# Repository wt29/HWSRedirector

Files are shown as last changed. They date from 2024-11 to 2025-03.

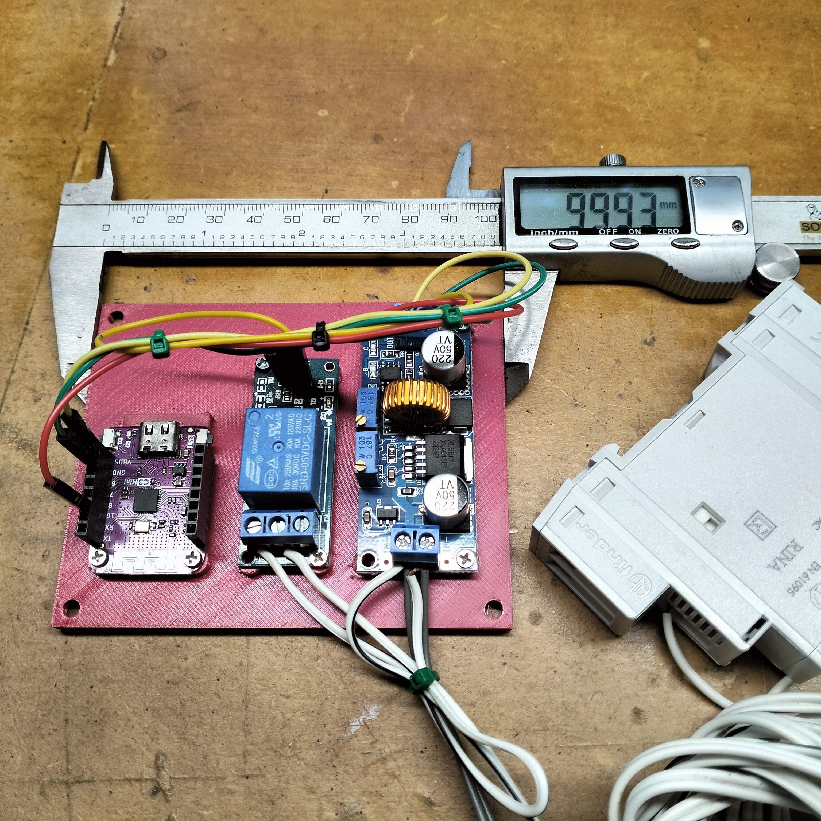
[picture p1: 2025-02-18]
IMG20250219094051.jpg

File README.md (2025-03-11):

# Hot Water System Redirector

Uses a 240V 25A contactor (with 12V triggering) to switch a resistive HWS into direct connection to the exported (from solar) grid. My
basic reason for this is - Heat Pumps are great for outright efficiency but are mechanical, expensive and will eventually wear out. A resistive HWS coupled with a 
decent sized solar array should be a better fit for a many homes (IMHO) especially those with limited funds for HPHWS installation.

This sketch uses an API to read from a power monitoring system - I use an IOTAWATT however it also has a "Shelly EM" interface as well.

If you are using EMONCMS as your data capture and management system, this will also log the changes there.

The sketch uses a small data.h file to store local values. It also allows me to upload this project without revealing local data. 
There is a template in the header of main.cpp. 

You can adjust the threshold value and the "wait time" depending on your local requirement.

Its currently set up for an Espressif ESP32 C3 (I use the LOLIN C3 Mini) however any ESP microcontroller should work. It assumes
the power monitoring is available via Wifi (they aren't much use without it).

Here is a basic BOM  

1. An ESP32/8266 with WiFi (they all have them) - I used a Lolin C3 Mini but almost any ESP thing would work. https://www.aliexpress.com/item/1005004740051202.html
2. 25A Contactor with 12V trigger - I used a "Finder 22.32" with both NC and NO contacts
3. 12V power supply - a 1A wall wart will do the job fine.
4. Small DC-DC converter to provide 5V to the ESP - https://core-electronics.com.au/dc-dc-adjustable-step-down-module-5a-75w.html  as an example
5. An Arduino style relay - https://core-electronics.com.au/5v-single-channel-relay-module-10a.html
6. Some sort of enclosure - this is only 12V and mounted outside the swithwoard so weather proofing is the main aim here.

Get a local sparky to hook up the contactor and required isolators. They can also expose the 12V terminals somewhere you can get to them outside the board. You may as well get them to install a local power point as well.

The repo contains a Fusion (360) project and STL to build a mounting board for the 3 electronic boards. There is also the KiCAD files for the (somewhat) basic circuit involved.

This project is also under a bit of occasional development, mainly around getting a small UI on it.

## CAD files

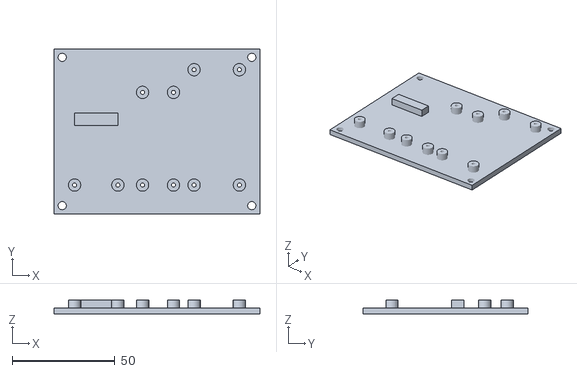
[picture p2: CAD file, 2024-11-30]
mount/HWSMount.stl
100.0 x 80.0 x 7.00

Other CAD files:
mount/HWS Redirector mount v5.f3d

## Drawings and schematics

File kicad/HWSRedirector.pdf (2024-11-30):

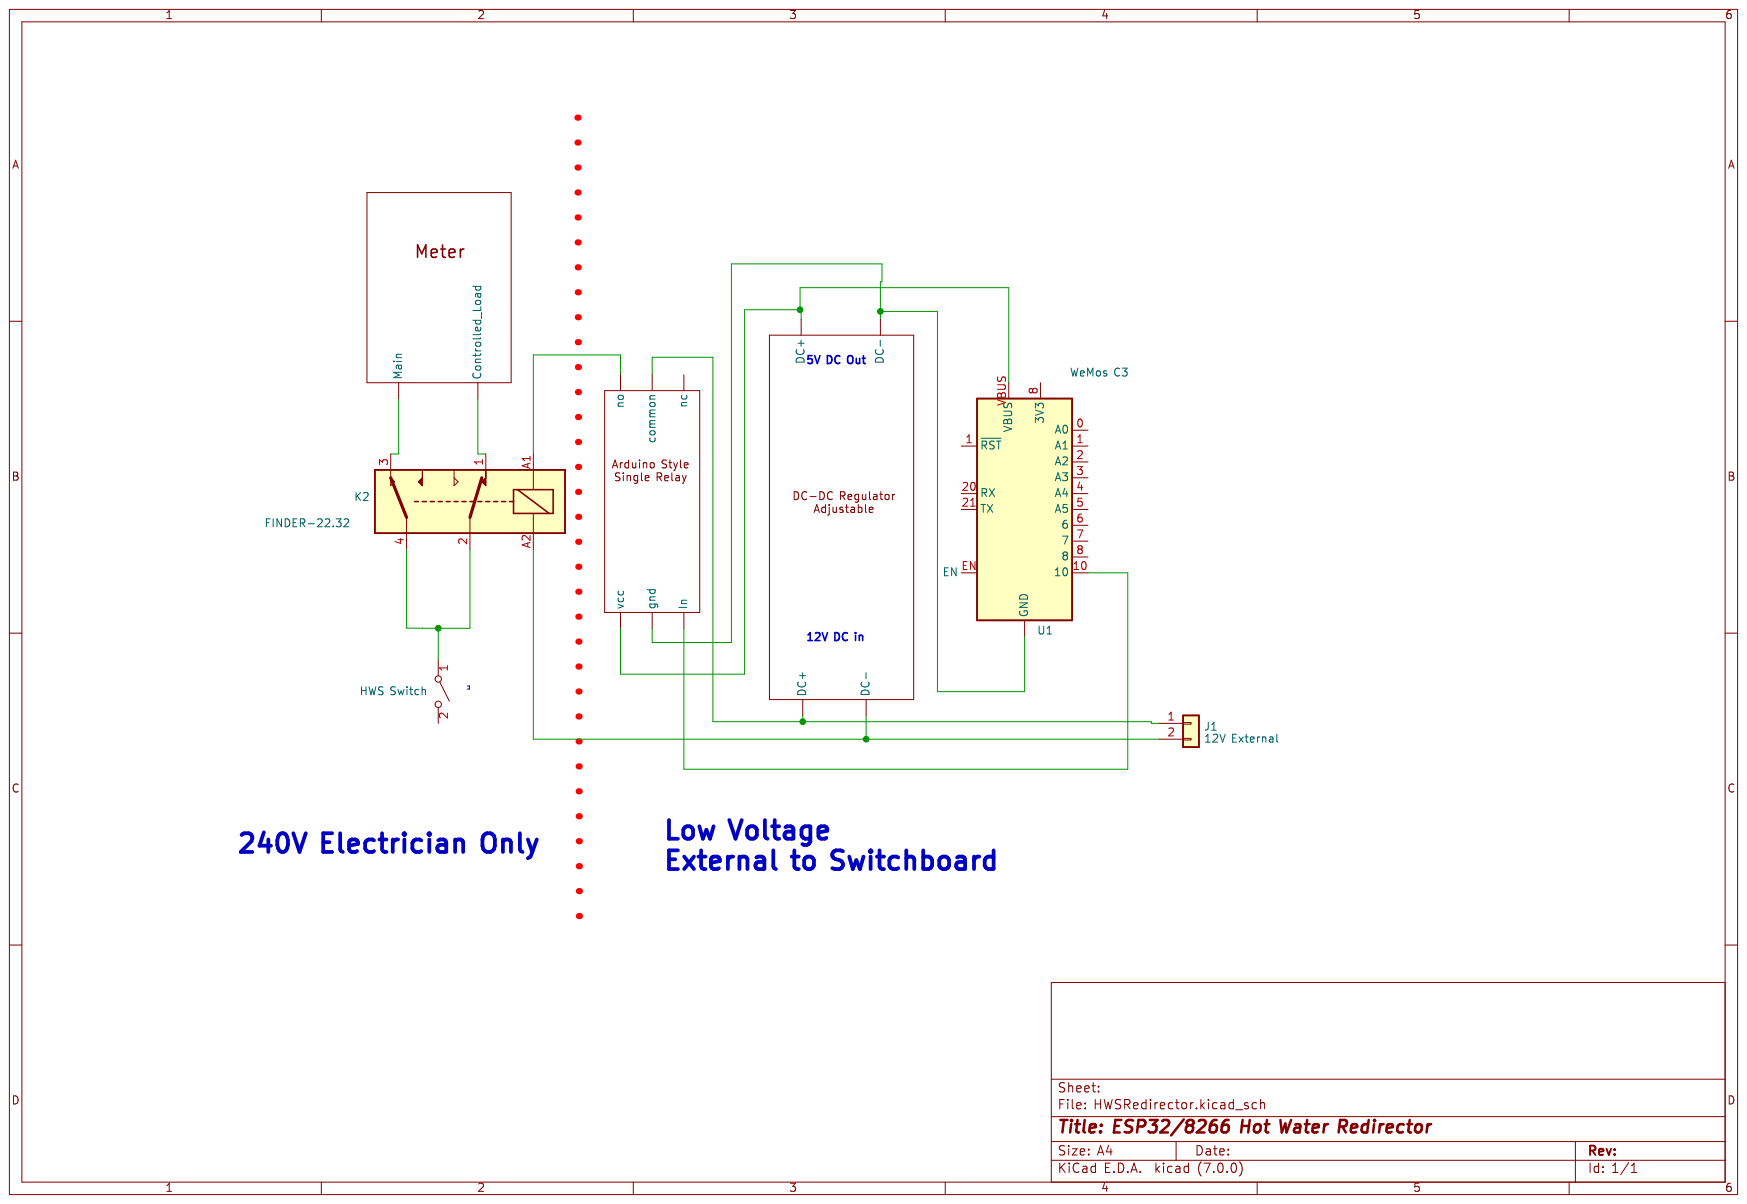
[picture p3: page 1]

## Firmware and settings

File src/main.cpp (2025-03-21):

#include <Arduino.h>

/*
  HWS Redirector

  This is designed to switch a resistive How Water System into grid power once a 
  local solar is exporting sufficient power.

  It utilises a 240V 25A contactor, with a 12V trigger to connect the HWS to the main/grid circuit.

  I uses a "Shelly EM" or and Iotawatt as the sense circuit and reads the local API for grid values

  It has a 5 minute timer to prevent the contactor cycling too often

  It is designed to use a Lolin C3 Mini but almost and ESP32/8266 with WiFi should work.
  
  https://lolin.aliexpress.com/store

  You will need a file "data.h" - copy the template below.
  
     -------------------------------------
  // template for data.h

  #define C3MINI                                 // Just incase you want to use something else
  
  // Node and Network Setup
  #define NODENAME "HWSRedirector"               // eg "Kitchen"  Required and UNIQUE per site.  Also used to find mdns eg NODENAME.local
  #define LOCAL_SSID "Your SSID"                 // How many you have defined
  #define LOCAL_PASSWD "Your local password"

  // API call to get grid value - sample Iotawatt shown - YMMV
    
  #define EMONCMS                              // You are logging to EMONCMS
  #define HOST       "Your EMONCMS HOST"       // Not required if not logging
  #define APIKEY     "Your EMONCMS API Key"    // Not required if not logging

  #define SHELLY                               // Using the Shelly EM and API
  #define API_CALL "http://192.168.1.100/query?select=[time.local.iso,Mains.Watts]&begin=m-1m&end=m&group=m&format=csv"
 -------------------------------------

How to put C3 boards into Device Firmware Upgrade (DFU) mode.

Hold on Button 9
Press Button Reset
Release Button 9 When you hear the prompt tone on usb reconnection

IMPORTANT -> if you don't setup the C3 WiFI output power parameter.... It doesn't connect!

*/
#define VERSION 0.2             // First Cut

#define C3MINI                  // This shoule work on almost any ESP32 BUT.... you will need to check your pin mappings.

#include <EEPROM.h>             // Going to save some the threshold value so it can be changed on the fly
#define EEPROM_SIZE 32          // 4 bytes each for wattsEnough and may be some other

#ifdef C3MINI               
 #include <WiFi.h>
 #include <ESPmDNS.h>
 #include <AsyncTCP.h>
//# include <WebServer.h>
 # include <ESPAsyncWebServer.h>
#else                            
// This should work if you are using an ESP8266
 #include <ESP8266WiFi.h>        // Should all works for and ESP8266
 #include <ESP8266WiFiMulti.h>   // Include the Wi-Fi-Multi library
 #include <ESP8266mDNS.h>
 #include <ESP8266WebServer.h>   // Include the WebServer library
#endif

#include <WiFiClient.h>
#include <ArduinoOTA.h>
#include <NTPClient.h>
#include <WiFiUdp.h>
#include <HTTPClient.h>

// Needed to move this here as the IPAddress types aren't declared until the WiFi libs are loaded
// This means we dont keep uploading API key+password to GitHub. (data.h should be ignored in repository)
#include "data.h"             // Create this file from template above.  

const char* nodeName = NODENAME;

#ifdef C3MINI
 AsyncWebServer server(80);
#else
 ESP8266WiFiMulti wifiMulti;      // Create an instance of the ESP8266WiFiMulti class, called 'wifiMulti'
 ESP8266WebServer server(80);     // Create a webserver object that listens for HTTP request on port 80
#endif
WiFiClient client;                // Instance of WiFi Client

String handleRoot();              // function prototypes for HTTP handlers
void handleNotFound();            // Something it don't understand

void millisDelay(long unsigned int);
bool connectWiFi();
String getInternetTime();

int gridWatts;
int hwsWatts;

int wattsEnough = -2200;          // Gets startup value, may not need once EEPROM code is OK
int waitTime = 300000;            // This is in milliseconds so 300000 is 60 x 5 x 1000
int contactorPin = 10;            // A relay or MOSFET to trigger the contactor - its likely to be 12V
bool contactorStatus = LOW;

const char* PARAM_INPUT_1 = "watts";
const char* PARAM_INPUT_2 = "seconds";

String inputWatts;
String inputSeconds;
String inputMessage;
String inputParam;
String inputMessage2;
String inputParam2;
    
#ifdef EMONCMS
const char* host = HOST;
const char* APIKEY = MYAPIKEY;
#endif

const uint32_t waitForWiFi = 5000 ;        // How long to wait for the WiFi to connect - 5 Seconds should be enough
int startWiFi;

int connectMillis = millis();              // this gets reset after every successful data push

int lastRun ;             

const long utcOffsetInSeconds = 36000;      // Sydney is 10 hours ahead - you will have to readjust
char daysOfTheWeek[7][12] = {"Sunday", "Monday", "Tuesday", "Wednesday", "Thursday", "Friday", "Saturday"};

// Define NTP Client to get time
WiFiUDP ntpUDP;
NTPClient timeClient(ntpUDP, "pool.ntp.org", utcOffsetInSeconds);
String timeString;
String startTime;
unsigned long startAbsoluteTime;    // How long have we been running for?

HTTPClient http;

const int ledPin = LED_BUILTIN;
int ledState = LOW;

void notFound(AsyncWebServerRequest* request) {
  request->send(404, "text/plain", "404: Not found"); // Send HTTP status 404 (Not Found) when there's no handler for the URI in the request
}

//-----------------------------------------
void setup()
{
  
  Serial.begin(115200);     // baud rate
  millisDelay(1) ;          // allow the serial to init
  Serial.println("--------Restart-------");         // clean up a little
  
  EEPROM.begin(32);                 // this number in "begin()" is ESP8266. EEPROM is emulated so you need buffer to emulate.

  int EEWatts;
  EEPROM.get(0, EEWatts );    // Should read 4 bytes for each of these thangs
  if ( isnan( EEWatts ) ) { 
    Serial.print("IsNan on wattsEnough");
    EEWatts = wattsEnough;
    EEPROM.put( 0, wattsEnough ) ;
    EEPROM.commit();
  } 
  Serial.print("Threshold watts from EEPROM:");
  Serial.println(EEWatts);
  wattsEnough = EEWatts;
  
  int EEWait;
  EEPROM.get(4,EEWait);        // Should read 4 bytes for each of these thangs
  if ( isnan( EEWait ) ) { 
    Serial.print("IsNan on WaitTime");
    EEWait = waitTime;               // Having issues during devel with "nan" (not a number) being written to EEPROM
    EEPROM.put(4,waitTime) ;
    EEPROM.commit();
  } 
  Serial.print("Threshold wait time from EEPROM:");
  Serial.println(EEWait);
  waitTime = EEWait;
  
  connectWiFi();                              // This thing isn't any use without WiFi

  pinMode( ledPin, OUTPUT );                  // The C3 V1 doesn't have an onboard LED
  pinMode( contactorPin, OUTPUT );            // Setup the relay/contactor
  digitalWrite( contactorPin, HIGH );         // Start with the (confusing) contactor open

  if (MDNS.begin( nodeName )) {               // Start the mDNS responder for <nodeName>.local
    Serial.println("mDNS responder started");
  }
  else
  {
    Serial.println("Error setting up MDNS responder!");
  }

  server.on("/", HTTP_GET, [](AsyncWebServerRequest *request) {
    Serial.println("ESP32 Web Server: New request received:");  // for debugging
    Serial.println("/");                                    // for debugging
    String html = handleRoot(); 
    request->send(200, "text/html", html );
    
    }
  );

  server.on("/ep", HTTP_GET, [] (AsyncWebServerRequest *request) {
    int W,S;
    EEPROM.get(0,W);
    EEPROM.get(4,S);
    Serial.println( "EEpromRead0 " + String(W) );
    Serial.println( "EEpromRead4 " + String(S) );
    request->send(200, "text/html", "EEPROM 0 returns: " + String(W) + "<br> EEPROM 4 returns: " + String(S) +
     "<br><br><a href=\"/\">Return to Home Page</a>");

    }
  );

  server.on("/get", HTTP_GET, [] (AsyncWebServerRequest *request) {
    Serial.println("ESP32 Web Server: New request received:");  // for debugging
    Serial.println("/get");                                    // for debugging
    inputWatts = String(wattsEnough);
    inputSeconds = String(waitTime);
    // GET input1 value on <ESP_IP>/get?input1=<inputMessage>
    if (request->hasParam(PARAM_INPUT_1)) {
      inputMessage = request->getParam(PARAM_INPUT_1)->value();
      inputParam = PARAM_INPUT_1;
      wattsEnough = inputMessage.toInt();
      Serial.println("wattsEnough:" + wattsEnough );
      
      EEPROM.put(0, wattsEnough);
      EEPROM.commit();
      request->send(200, "text/html", "HTTP GET request sent to your ESP on input field (" 
        + inputParam + ") with value: " + inputMessage +
        "<br><br><a href=\"/\">Return to Home Page</a>");
    }
    // GET input2 value on <ESP_IP>/get?input2=<inputMessage>
    if (request->hasParam(PARAM_INPUT_2)) {
      inputMessage2 = request->getParam(PARAM_INPUT_2)->value();
      inputParam2 = PARAM_INPUT_2;
      waitTime = inputMessage2.toInt();    // Need to get this up from millis
      waitTime=waitTime*1000;
      Serial.println("waitTime:" + String(waitTime) );

      EEPROM.put(4, waitTime);
      EEPROM.commit();
      request->send(200, "text/html", "HTTP GET request sent to your ESP on input field (" 
        + inputParam2 + ") with value: " + inputMessage2 +
        "<br><br><a href=\"/\">Return to Home Page</a>");
    }
  }  
);
  server.onNotFound( notFound );
  
  server.on("/reboot", HTTP_GET, [](AsyncWebServerRequest *request) {
    request->send(200, "text/html", "Rebooting in 5 seconds <br>After reboot, click <a href=\"/\">Return to Home Page</a>");
    Serial.println( "Rebooting....." );
    millisDelay( 5000 );
    ESP.restart();
}
  );

  // Start the server
  server.begin();

  ArduinoOTA.begin();                           // Remote updates
  ArduinoOTA.setHostname( nodeName );

  timeClient.begin();
  startTime = getInternetTime();
  startAbsoluteTime = timeClient.getEpochTime();

  lastRun -= waitTime;  // Should force a poll on startup

}       // Setup

//------------------------------------------------------

void loop() {

  ArduinoOTA.handle();                            // Process updates

  bool trigger =  ( millis() > lastRun + waitTime ) ;
  if ( trigger )   {                                // only want this happening every 5 minutes (or so) 
    lastRun = millis();                           // don't want to add Wifi Connection latency to the poll
   
    Serial.println();
    Serial.print("Free Heap : ");
    Serial.println(ESP.getFreeHeap());

    if ( connectWiFi() ) {;                        // Also just checks if Wifi is connected
    
      String gridPath = IW_GRID;
      String hwsPath = IW_HWS;
      
      http.begin(client,gridPath);
      
      // Send HTTP GET request
      int httpResponseCode = http.GET();    // Check to see if API is responding
      
      if (httpResponseCode>0) {
        Serial.print("API HTTP Response code: ");
        Serial.println(httpResponseCode);

        String API_GridPayload = http.getString();
        http.end();

        http.begin(client,hwsPath);
        int httpResponseCode = http.GET();     // Check to see if API is responding
        String API_HWSPayload = http.getString();
        http.end();

#ifndef SHELLY            // i.e. Iotawatt    
        gridWatts = API_GridPayload.substring(API_GridPayload.indexOf(',')+ 1).toInt();
        hwsWatts = API_HWSPayload.substring(API_HWSPayload.indexOf(',')+ 1).toInt();
#else        
        // Required bits to extract Shelly GRID payload.
        // This is a sample Shelly EM output
        // String API_payload = "{\"power\":-3000.76,\"reactive\":105.32,\"pf\":-0.49,\"voltage\":247.49,\"is_valid\":true,\"total\":323084.2,\"total_returned\":2311187.4}";
        gridWatts = API_payload.substring(API_payload.indexOf(':')+ 1).toInt();
        hwsWatts = API_payload.substring(API_payload.indexOf(':')+ 1).toInt();  // Needs to be adjusted

#endif
        Serial.print("Grid Value: ");
        Serial.println(gridWatts);
        Serial.print("HWS Value: ");
        Serial.println( hwsWatts);
}
       else 
       {
        Serial.print("Error code: ");
        Serial.println(httpResponseCode);
       }


       Serial.println( "WattEnough * 1-: " + String( wattsEnough *-1 ));
       
       if ( ( (gridWatts + wattsEnough) < 0 ) | ( ( gridWatts + hwsWatts) < 0 ) ) {   // When in export, grid watts will be in negative so we need the grid
                                                                                      // to be less (more negative) then 'wattsEnough' 
                                                                                      // Need to check if the HWS is already on. In that case ANY export is enough
        contactorStatus = LOW;                // Relay is energised on LOW signal
        Serial.print( "Contactor on at " + getInternetTime() );
       }
       else
       {
        contactorStatus = HIGH;           // Default position 
        Serial.print( "Contactor off at " + getInternetTime() );
       }
       digitalWrite( contactorPin, contactorStatus );    // confusing because the relay is energised on a low signal

#ifdef EMONCMS       
       Serial.printf("[Connecting to %s ... \n", host );
      
       if (client.connect(host, 80))     {
        Serial.println("Connected]");
        Serial.println("[Sending a request]");

        String request  = "GET " ;
            request += "/input/post?node=";
            request += nodeName;
            request += "&fulljson={\"HWSRedirector\":";
            request += ( contactorStatus ? 0 : 1 ) ;    // Reverse logic again
            request += ",\"Export\":" ;
            request +=  gridWatts * -1;
            request += ",\"WaitTime\":" ;
            request += waitTime/1000 ;                  // Seconds is enough
            request += ",\"Threshold\":" ;
            request += wattsEnough ;
            request += "}&apikey=";
            request += APIKEY; 

        Serial.println( request );
        client.println( request );

        Serial.println("[Response:]");

        while (client.connected()) {
         if (client.available()) {
          String resp = "Null";
          resp = client.readStringUntil('\n');  // See what the host responds with.
          Serial.println( resp );

        }
#endif
      } 
     }
    }     // Connect WiFi
  }      // Millis Loop
}       // Loop

boolean connectWiFi() {
int start = millis();  
 
if ( WiFi.status() == WL_CONNECTED) {   // No point doing this if connected
 return true;
}
else                                    // Attempt
{ 
 WiFi.mode(WIFI_STA);                   // Station Mode
 WiFi.hostname( nodeName );             // This will show up in your DHCP server
 WiFi.disconnect();  
 WiFi.begin(LOCAL_SSID, LOCAL_PASSWD);
 
#ifdef C3MINI
 WiFi.setTxPower(WIFI_POWER_8_5dBm);    // This is a C3 thing
#endif

Serial.print("Connecting");
 while ( millis() < start + 5000) {     // 5 seconds to connect 
 
   delay(500);
   Serial.print(".");
  
   if ( WiFi.status() == WL_CONNECTED ) {
    Serial.println();
    Serial.print("Connected, IP address: ");
    Serial.println(WiFi.localIP());

    Serial.println("");
    Serial.print("IP Address: ");
    Serial.println( WiFi.localIP());
    Serial.printf("Connection status: %d\n", WiFi.status());
    return true;
    }
  }
 }
 // Abject failure - we couldn't connect
 Serial.println("");
 Serial.printf("Connection status: %d\n", WiFi.status());
 return false;              
}

String handleRoot() {
  String response =  "<h2>You have reached the Hot Water System Redirector</h2>";
  response += "<b>This triggers at " + String( waitTime/60000 ) + " minute intervals and when the export power value reaches " + String( abs( wattsEnough ) ) + " Watts</b>";
  response += "<body><p></p><table style=\"width:600\">";
  response += "<tr><td>Current time </td><td><b>" + getInternetTime() + "</b></td></tr>";
  int runSecs = timeClient.getEpochTime() - startAbsoluteTime;
  int upDays = abs( runSecs / 86400 );
  int upHours = abs( runSecs - ( upDays * 86400 ) ) / 3600;
  int upMins = abs( ( runSecs - (upDays * 86400) - ( upHours * 3600 ) ) / 60 ) ;
  int upSecs = abs( runSecs - (upDays * 86400) - ( upHours * 3600 ) - ( upMins * 60 ) );
  String upTime = String(upDays) + "d " + String( upHours ) + "h " + String(upMins) + "m " + String(upSecs) + "s";

  response += "<tr><td>Uptime  </td><td><b>" + upTime + "</b></td></tr>";
  response += "<tr><td>Node Name </td><td><b>" + String(nodeName) + "</b></td></tr>";
  response += "<tr><td>Local IP is: </td><td><b>" + WiFi.localIP().toString() + "</b></td></tr>";
  response += "<tr><td>Connected via AP:</td><td> <b>" + WiFi.SSID() + "</b></td></tr>";
  response += "<tr><td>Free Heap Space </td><td><b>" + String(ESP.getFreeHeap()) + " bytes</b></td></tr>";
  response += "<tr><td>Software Version</td><td><b>" + String(VERSION) + "</b></td></tr>";
  response += "<tr></tr>";
  response += "<tr><td>Grid watts </td><td><b>" + String(gridWatts) + " Negative is EXPORT </td></tr>";
  response += "<tr><td>HWS watts </td><td><b>" + String(hwsWatts) + "</td></tr>";
  response += "<tr><td>Contactor Status </td><td><b>" + String( (contactorStatus ? "Off" : "On" ) ) + "</td></tr>";
  response += "<tr><td>Current trigger value (in watts) </td><td><b>" + String( wattsEnough ) + "</b></td></tr>";  // this value is negative in the code but don't want to confuse users
  response += "<tr><td>    Current poll time in milliseconds </td><td><b>" + String( waitTime ) + "</b></td></tr>";
  response += "</table>";
  response += "<br>";
  response += "<form action=\"/get\">";
  response += "Trigger value in watts: <input type=\"text\" name=\"watts\">";
  response += "<input type=\"submit\" value=\"Submit\">";
  response += "</form>";
  response += "<form action=\"/get\">";
  response += " Poll time in seconds: <input type=\"text\" name=\"seconds\">";
  response += "<input type=\"submit\" value=\"Submit\">";
  response += "</form><br>";
  response += "This server also responds to /reboot</body>";
  return response;
}


String getInternetTime() {
  timeClient.update();
  return String( timeClient.getFormattedTime() );
}

// Wait around for a bit - This allows interupts to run whilst waiting
void millisDelay ( long unsigned int mDelay )
{
  long unsigned int now = millis();
  do {
    // Do nothing
  } while ( millis() < now + mDelay);

}

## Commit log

2024-11-30 Add Kicad Files
2024-11-30 add Kicad
    [HWSRedirector.kicad_pcb, HWSRedirector.kicad_sch]
2024-11-30 add mount details
    [HWS Redirector mount v5.f3d, HWSMount.stl]
2024-12-03 Futzing around the edges
    [Opener.stl]
2025-01-24 Updated the schematic
    [HWSRedirector.kicad_sch, Opener.stl]
2025-03-11 Web Server adjust of parameters fixed
    [main.cpp]
